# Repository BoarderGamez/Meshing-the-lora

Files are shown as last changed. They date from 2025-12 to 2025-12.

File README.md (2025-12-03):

# Meshing the LoRa
This is a compact LoRa puck for all your needs such as meshtastic. I made this because I'm on my way to getting my ham radio licence and I thought this would be a cool accompanying thing. (also meshtastic is peak)
## Where did this name come from?
I intend to use it for meshtastic so I thought of this name!





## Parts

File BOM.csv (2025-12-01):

Index | LCSC# | MPN | Manufacturer | Package | Description | RoHS | Quantity | MOQ | Multiple | Unit Price($) | Extended Price($) | Product Link | Total Price ($)
1 | C92361 | CL05A474KA5NNNC | Samsung Electro-Mechanics | 402 | 25V 470nF X5R ±10% 0402 Ceramic Capacitors RoHS | yes | 10 | 10 | 10 | 0.0118 | 0.12 | https://www.lcsc.com/product-detail/C92361.html | 0.12
2 | C1525 | CL05B104KO5NNNC | Samsung Electro-Mechanics | 402 | 16V 100nF X7R ±10% 0402 Ceramic Capacitors RoHS | yes | 100 | 100 | 100 | 0.0012 | 0.12 | https://www.lcsc.com/product-detail/C1525.html | 0.24
3 | C1864241 | GJM1555C1H390GB01D | muRata | 402 | 50V 39pF C0G ±2% 0402 Ceramic Capacitors RoHS | yes | 20 | 20 | 20 | 0.0355 | 0.71 | https://www.lcsc.com/product-detail/C1864241.html | 0.95
4 | C76906 | GJM1555C1H3R3BB01D | muRata | 402 | 50V 3.3pF C0G 0402 Ceramic Capacitors RoHS | yes | 50 | 50 | 50 | 0.0166 | 0.83 | https://www.lcsc.com/product-detail/C76906.html | 1.78
5 | C77018 | GRM155R71H102KA01D | muRata | 402 | 50V 1nF X7R ±10% 0402 Ceramic Capacitors RoHS | yes | 100 | 100 | 100 | 0.002 | 0.2 | https://www.lcsc.com/product-detail/C77018.html | 1.98
6 | C76970 | GRM1555C1H470JA01D | muRata | 402 | 50V 47pF C0G ±5% 0402 Ceramic Capacitors RoHS | yes | 100 | 100 | 100 | 0.0022 | 0.22 | https://www.lcsc.com/product-detail/C76970.html | 2.2
7 | C307339 | CL05B473KB5VPNC | Samsung Electro-Mechanics | 402 | 50V 47nF X7R ±10% 0402 Ceramic Capacitors RoHS | yes | 100 | 100 | 100 | 0.0076 | 0.76 | https://www.lcsc.com/product-detail/C307339.html | 2.96
8 | C14445 | CL05A105KP5NNNC | Samsung Electro-Mechanics | 402 | 10V 1uF X5R ±10% 0402 Ceramic Capacitors RoHS | yes | 100 | 100 | 100 | 0.0017 | 0.17 | https://www.lcsc.com/product-detail/C14445.html | 3.13
9 | C76950 | GRM1555C1H150JA01D | muRata | 402 | 50V 15pF C0G ±5% 0402 Ceramic Capacitors RoHS | yes | 100 | 100 | 100 | 0.0025 | 0.25 | https://www.lcsc.com/product-detail/C76950.html | 3.38
10 | C315248 | CL05A106MP5NUNC | Samsung Electro-Mechanics | 402 | 10V 10uF X5R ±20% 0402 Ceramic Capacitors RoHS | yes | 20 | 20 | 20 | 0.0085 | 0.17 | https://www.lcsc.com/product-detail/C315248.html | 3.55
11 | C85815 | BLM15AX102SN1D | muRata | 402 | 490mΩ ±25% 1kΩ@100MHz 0402 Ferrite Beads and Chips RoHS | yes | 100 | 100 | 100 | 0.0055 | 0.55 | https://www.lcsc.com/product-detail/C85815.html | 4.1
12 | C5224443 | 0900FM15K0039E | Johanson Dielectrics | SMD-10P,1.2x2mm | SMD-10P,1.2x2mm Ceramic Filters RoHS | yes | 2 | 1 | 1 | 1.8851 | 3.77 | https://www.lcsc.com/product-detail/C5224443.html | 7.87
13 | C3025063 | USB4105-GF-A-060 | Global Connector Technology | SMD | SMD USB, DVI, HDMI Connector Assemblies RoHS | yes | 2 | 1 | 1 | 1.0013 | 2 | https://www.lcsc.com/product-detail/C3025063.html | 9.87
14 | C3221788 | LQW15DN150M00D | muRata | 402 | 15uH 100mA 0402 Fixed Inductors RoHS | yes | 2 | 1 | 1 | 1.1864 | 2.37 | https://www.lcsc.com/product-detail/C3221788.html | 12.24
15 | C337956 | LQW15AN9N1H00D | muRata | 402 | 9.1nH Unshielded Inductor 0402 Fixed Inductors RoHS | yes | 10 | 10 | 10 | 0.0388 | 0.39 | https://www.lcsc.com/product-detail/C337956.html | 12.63
16 | C22334 | LQW15AN47NG00D | muRata | 402 | 47nH Unshielded Inductor 0402 Fixed Inductors RoHS | yes | 20 | 20 | 20 | 0.0365 | 0.73 | https://www.lcsc.com/product-detail/C22334.html | 13.36
17 | C413063 | ERJ2RKF1000X | PANASONIC | 402 | 100mW 100Ω ±100ppm/℃ Thick Film Resistor ±1% 0402 Chip Resistor - Surface Mount RoHS | yes | 100 | 100 | 100 | 0.0047 | 0.47 | https://www.lcsc.com/product-detail/C413063.html | 13.83
18 | C191123 | ERJ2RKF1002X | PANASONIC | 402 | 100mW 10kΩ 50V ±100ppm/℃ Thick Film Resistor ±1% 0402 Chip Resistor - Surface Mount RoHS | yes | 100 | 100 | 100 | 0.0045 | 0.45 | https://www.lcsc.com/product-detail/C191123.html | 14.28
19 | C2076786 | ERJ2RKF27R4X | PANASONIC | 402 | 100mW 27.4Ω 50V ±100ppm/℃ Thick Film Resistor ±1% 0402 Chip Resistor - Surface Mount RoHS | yes | 50 | 50 | 50 | 0.0057 | 0.29 | https://www.lcsc.com/product-detail/C2076786.html | 14.57
20 | C242161 | ERJ2RKF1001X | PANASONIC | 402 | 100mW 1kΩ ±100ppm/℃ Thick Film Resistor ±1% 0402 Chip Resistor - Surface Mount RoHS | yes | 100 | 100 | 100 | 0.0049 | 0.49 | https://www.lcsc.com/product-detail/C242161.html | 15.06
21 | C105872 | RC0402FR-075K1L | YAGEO | 402 | 5.1kΩ 62.5mW 50V ±100ppm/℃ Thick Film Resistor ±1% 0402 Chip Resistor - Surface Mount RoHS | yes | 100 | 100 | 100 | 0.0007 | 0.07 | https://www.lcsc.com/product-detail/C105872.html | 15.13
22 | C2689642 | PTS636SK25SMTRLFS | C&K | SMD,6x3.5mm | 12V Rectangular Button SPST-NO 50mA SMD,6x3.5mm Tactile Switches RoHS | yes | 5 | 5 | 5 | 0.3601 | 1.8 | https://www.lcsc.com/product-detail/C2689642.html | 16.93
23 | C191341 | SX1262IMLTRT | SEMTECH | QFN-24-EP(4x4) | 300Kbps General Purpose ISM <1 GHz SPI -148dBm 150MHz~960MHz QFN-24-EP(4x4) RF Transceiver ICs RoHS | yes | 1 | 1 | 1 | 3.1633 | 3.16 | https://www.lcsc.com/product-detail/C191341.html | 20.09
24 | C2040 | RP2040 | Raspberry Pi | LQFN-56(7x7) | 133MHz 30 LQFN-56(7x7) Microcontrollers RoHS | yes | 1 | 1 | 1 | 0.9482 | 0.95 | https://www.lcsc.com/product-detail/C2040.html | 21.04
25 | C97521 | W25Q128JVSIQ | Winbond | SOIC-8-208mil | 128Mbit 2.7V~3.6V 133MHz SPI SOIC-8-208mil Memory (ICs) RoHS | yes | 1 | 1 | 1 | 1.8032 | 1.8 | https://www.lcsc.com/product-detail/C97521.html | 22.84
26 | C51118 | AP2112K-3.3TRG1 | DIODES | SOT-25-5 | 65dB@(1kHz) Positive Fixed 3.3V SOT-25-5 Voltage Regulators - Linear, Low Drop Out (LDO) Regulators RoHS | yes | 5 | 5 | 5 | 0.1344 | 0.67 | https://www.lcsc.com/product-detail/C51118.html | 23.51
27 | C470892 | PE4259-63 | pSemi | SC-70-6 | 30dB 0.35dB SC-70-6 RF Switches RoHS | yes | 1 | 1 | 1 | 0.5777 | 0.58 | https://www.lcsc.com/product-detail/C470892.html | 24.09
28 | C276421 | ABM8G-12.000MHZ-B4Y-T | ABRACON | SMD3225-4P | 10pF SMD3225-4P Crystals RoHS | yes | 2 | 1 | 1 | 0.454 | 0.91 | https://www.lcsc.com/product-detail/C276421.html | 25
29 | C5187559 | ABM8G-32.000MHZ-B4Y-T | ABRACON | SMD3225-4P | SMD3225-4P Crystals RoHS | yes | 2 | 1 | 1 | 0.7108 | 1.42 | https://www.lcsc.com/product-detail/C5187559.html | 26.42
30 | N/A | Shipping global direct |  |  |  |  |  |  |  |  | 9.13 |  | 35.55
31 | N/A | JLCPCB excl shipping |  |  | green+stencil |  |  |  |  |  | 14.08 |  | 49.63
32 |  | Shipping europacket bc cheaper than standard direct |  |  | 1 eur cheaper approx |  |  |  |  |  | 20.36 |  | 69.99
33 |  | Customs |  |  |  |  |  |  |  |  | 8.3 |  | 78.29

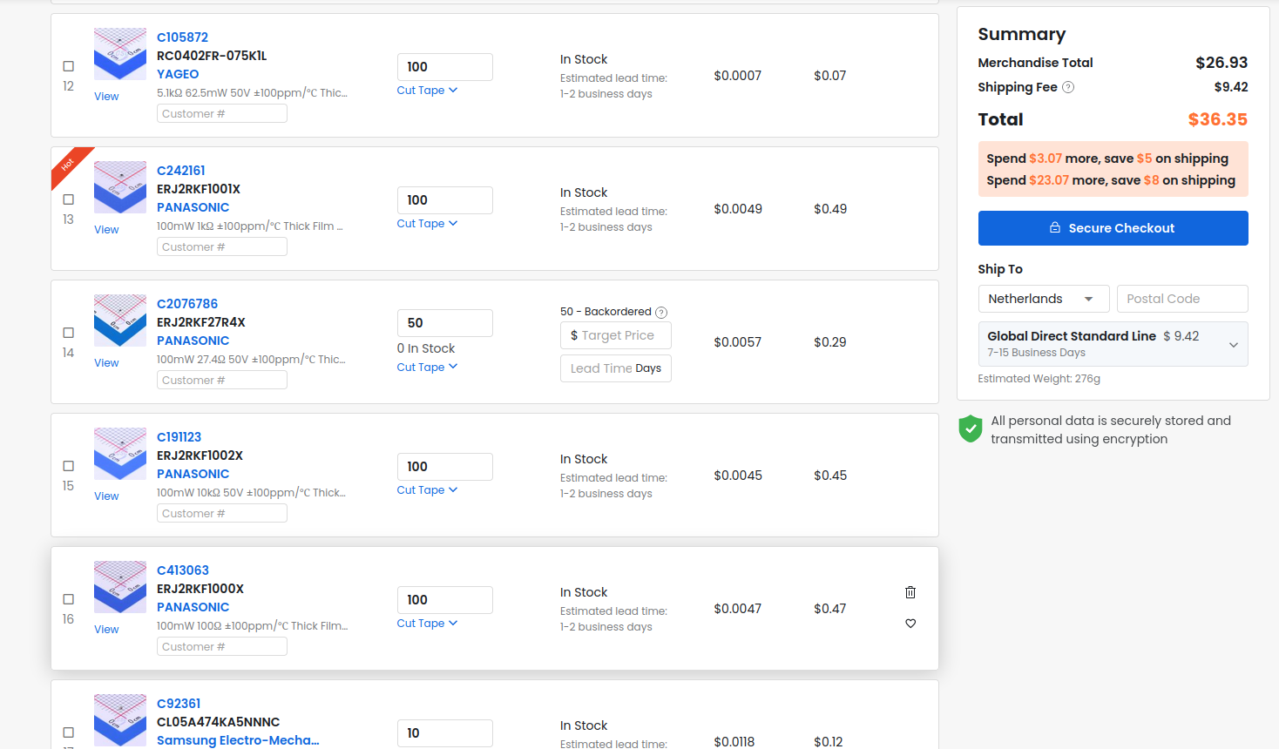
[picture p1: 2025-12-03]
costs/Screenshot from 2025-12-03 13-56-53.png

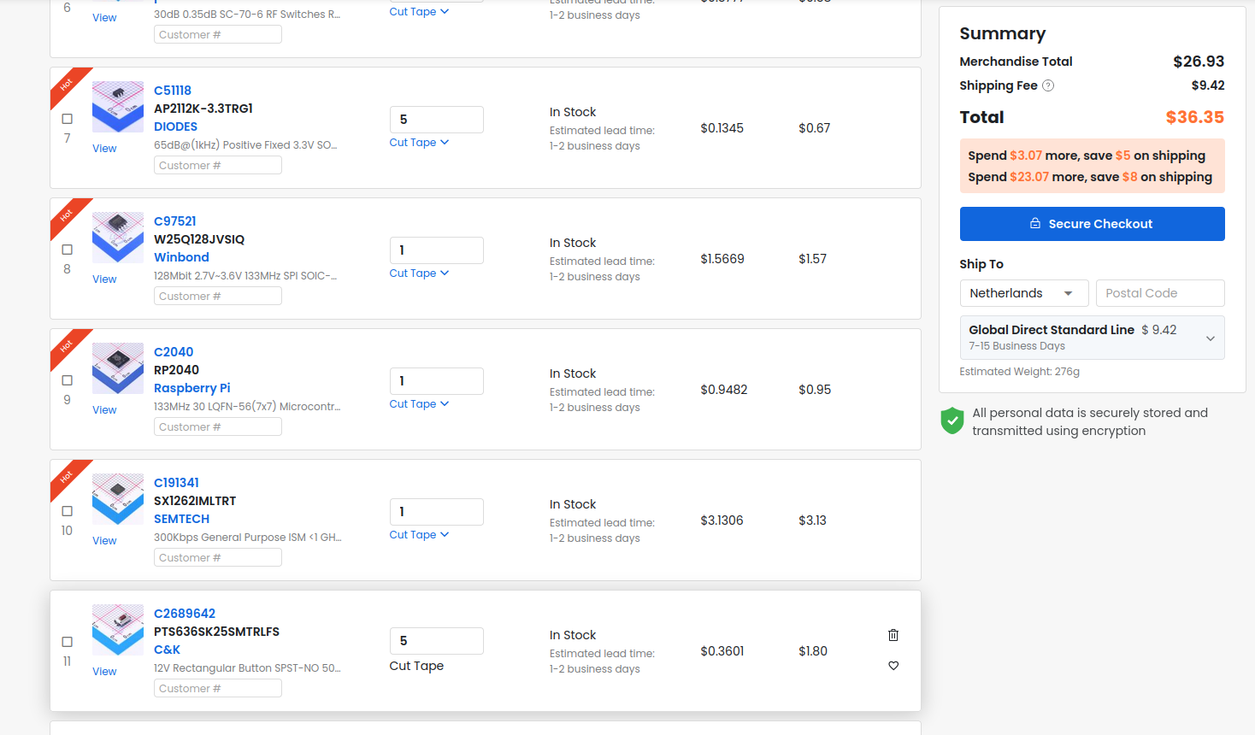
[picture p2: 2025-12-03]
costs/Screenshot from 2025-12-03 13-56-49.png

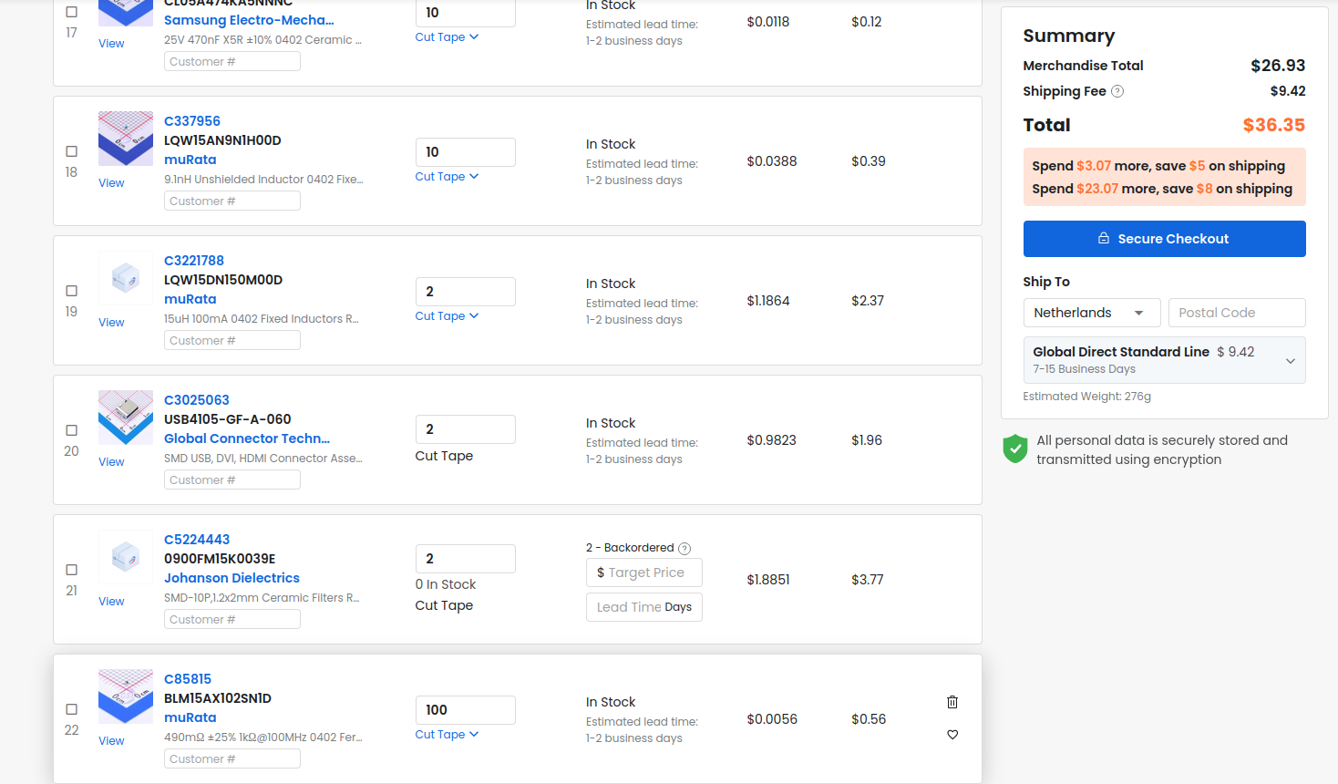
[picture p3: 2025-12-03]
costs/Screenshot from 2025-12-03 13-56-58.png

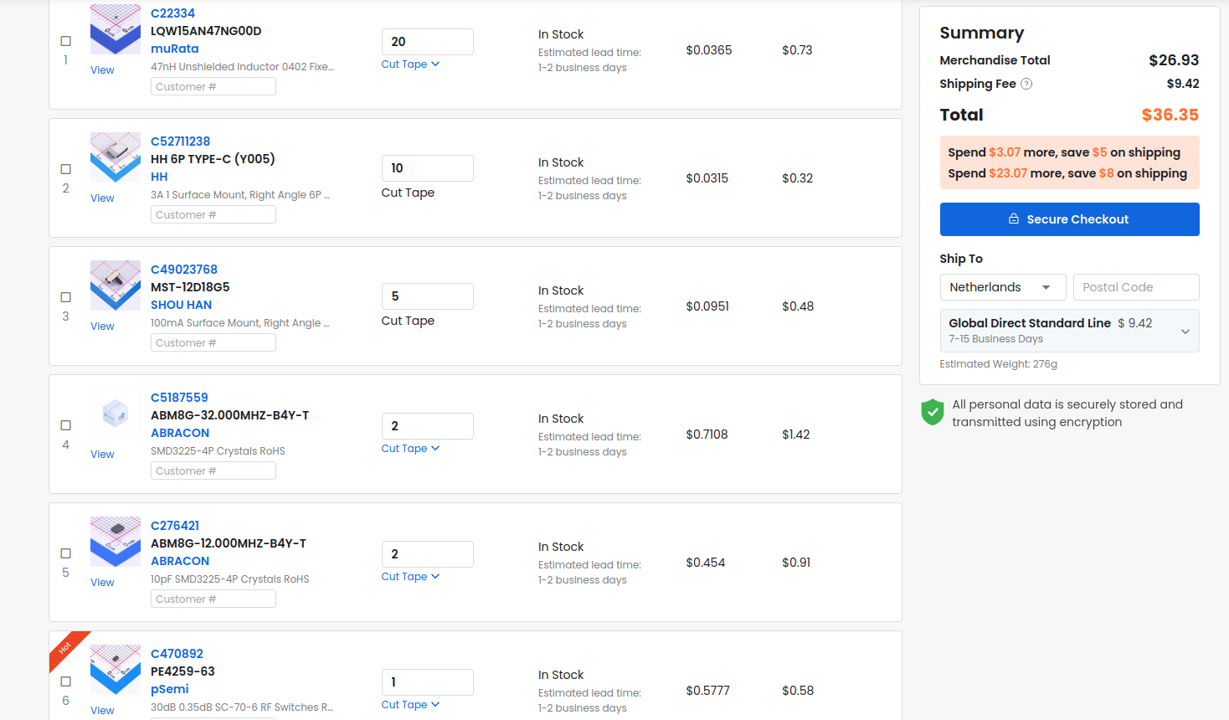
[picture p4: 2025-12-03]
costs/Screenshot from 2025-12-03 13-56-42.png

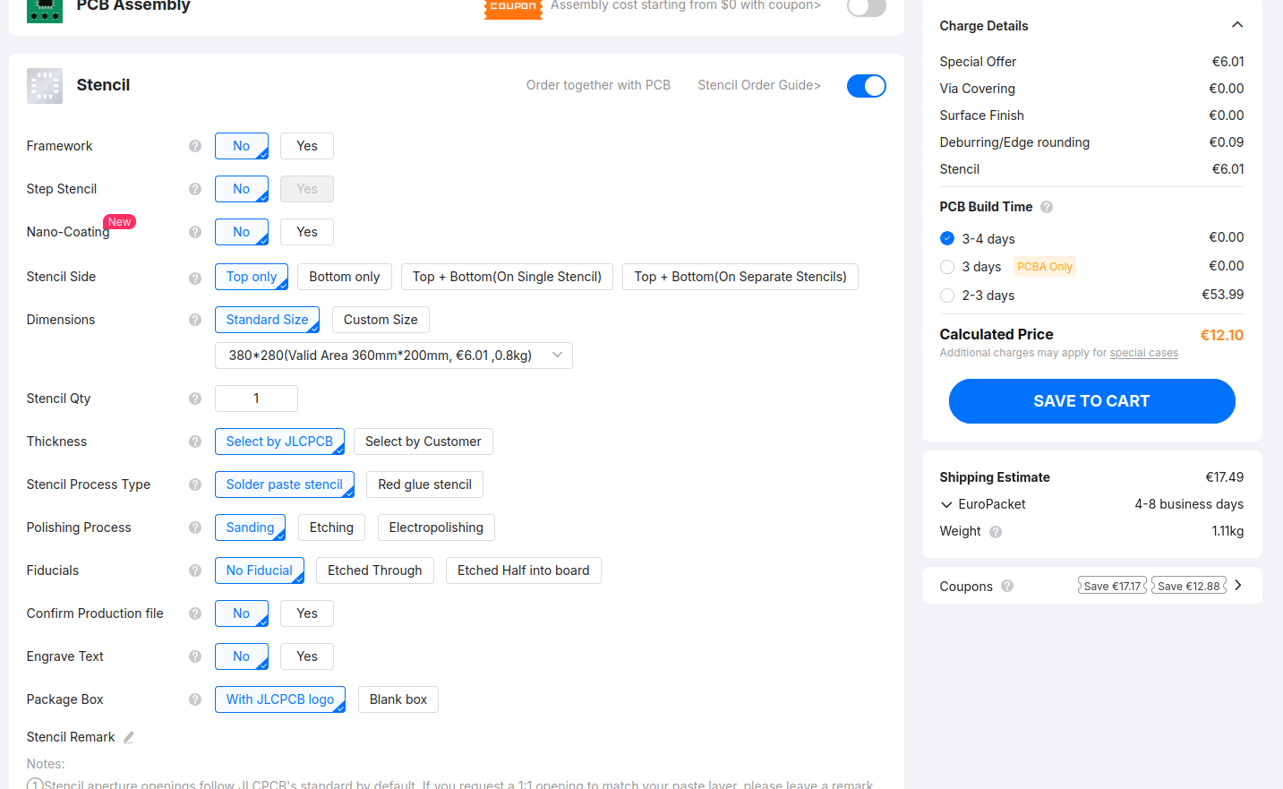
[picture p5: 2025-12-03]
costs/Screenshot from 2025-12-03 14-10-08.png

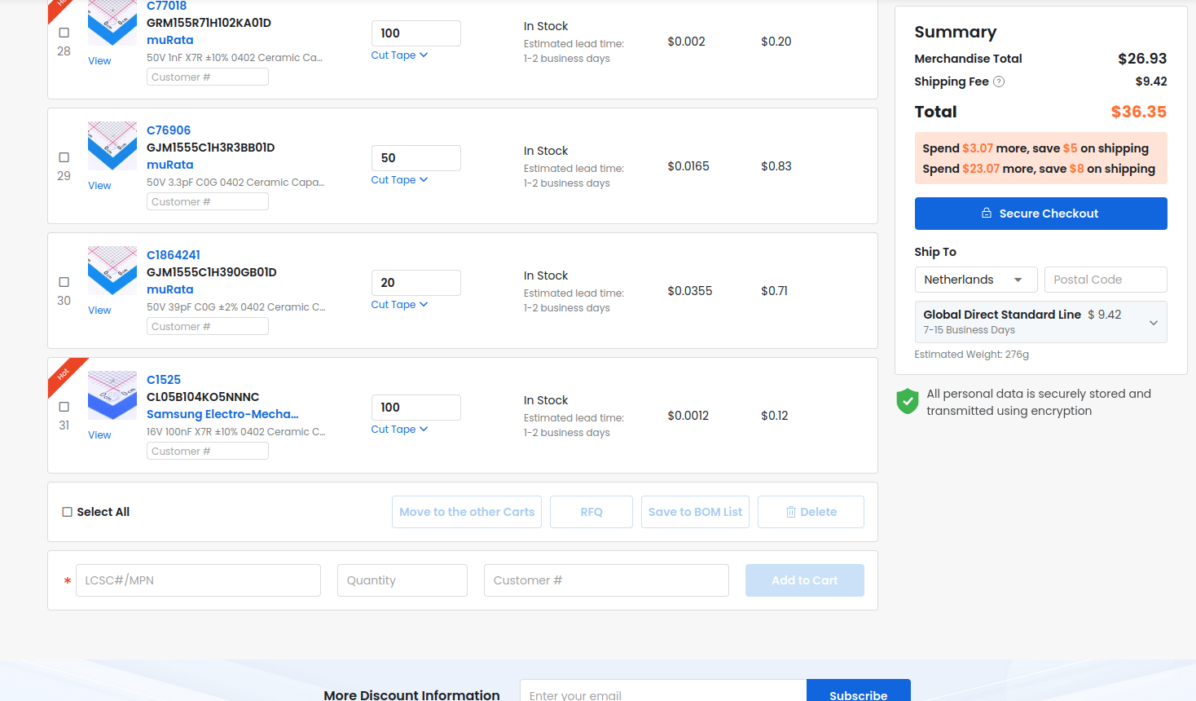
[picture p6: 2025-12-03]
costs/Screenshot from 2025-12-03 13-57-06.png

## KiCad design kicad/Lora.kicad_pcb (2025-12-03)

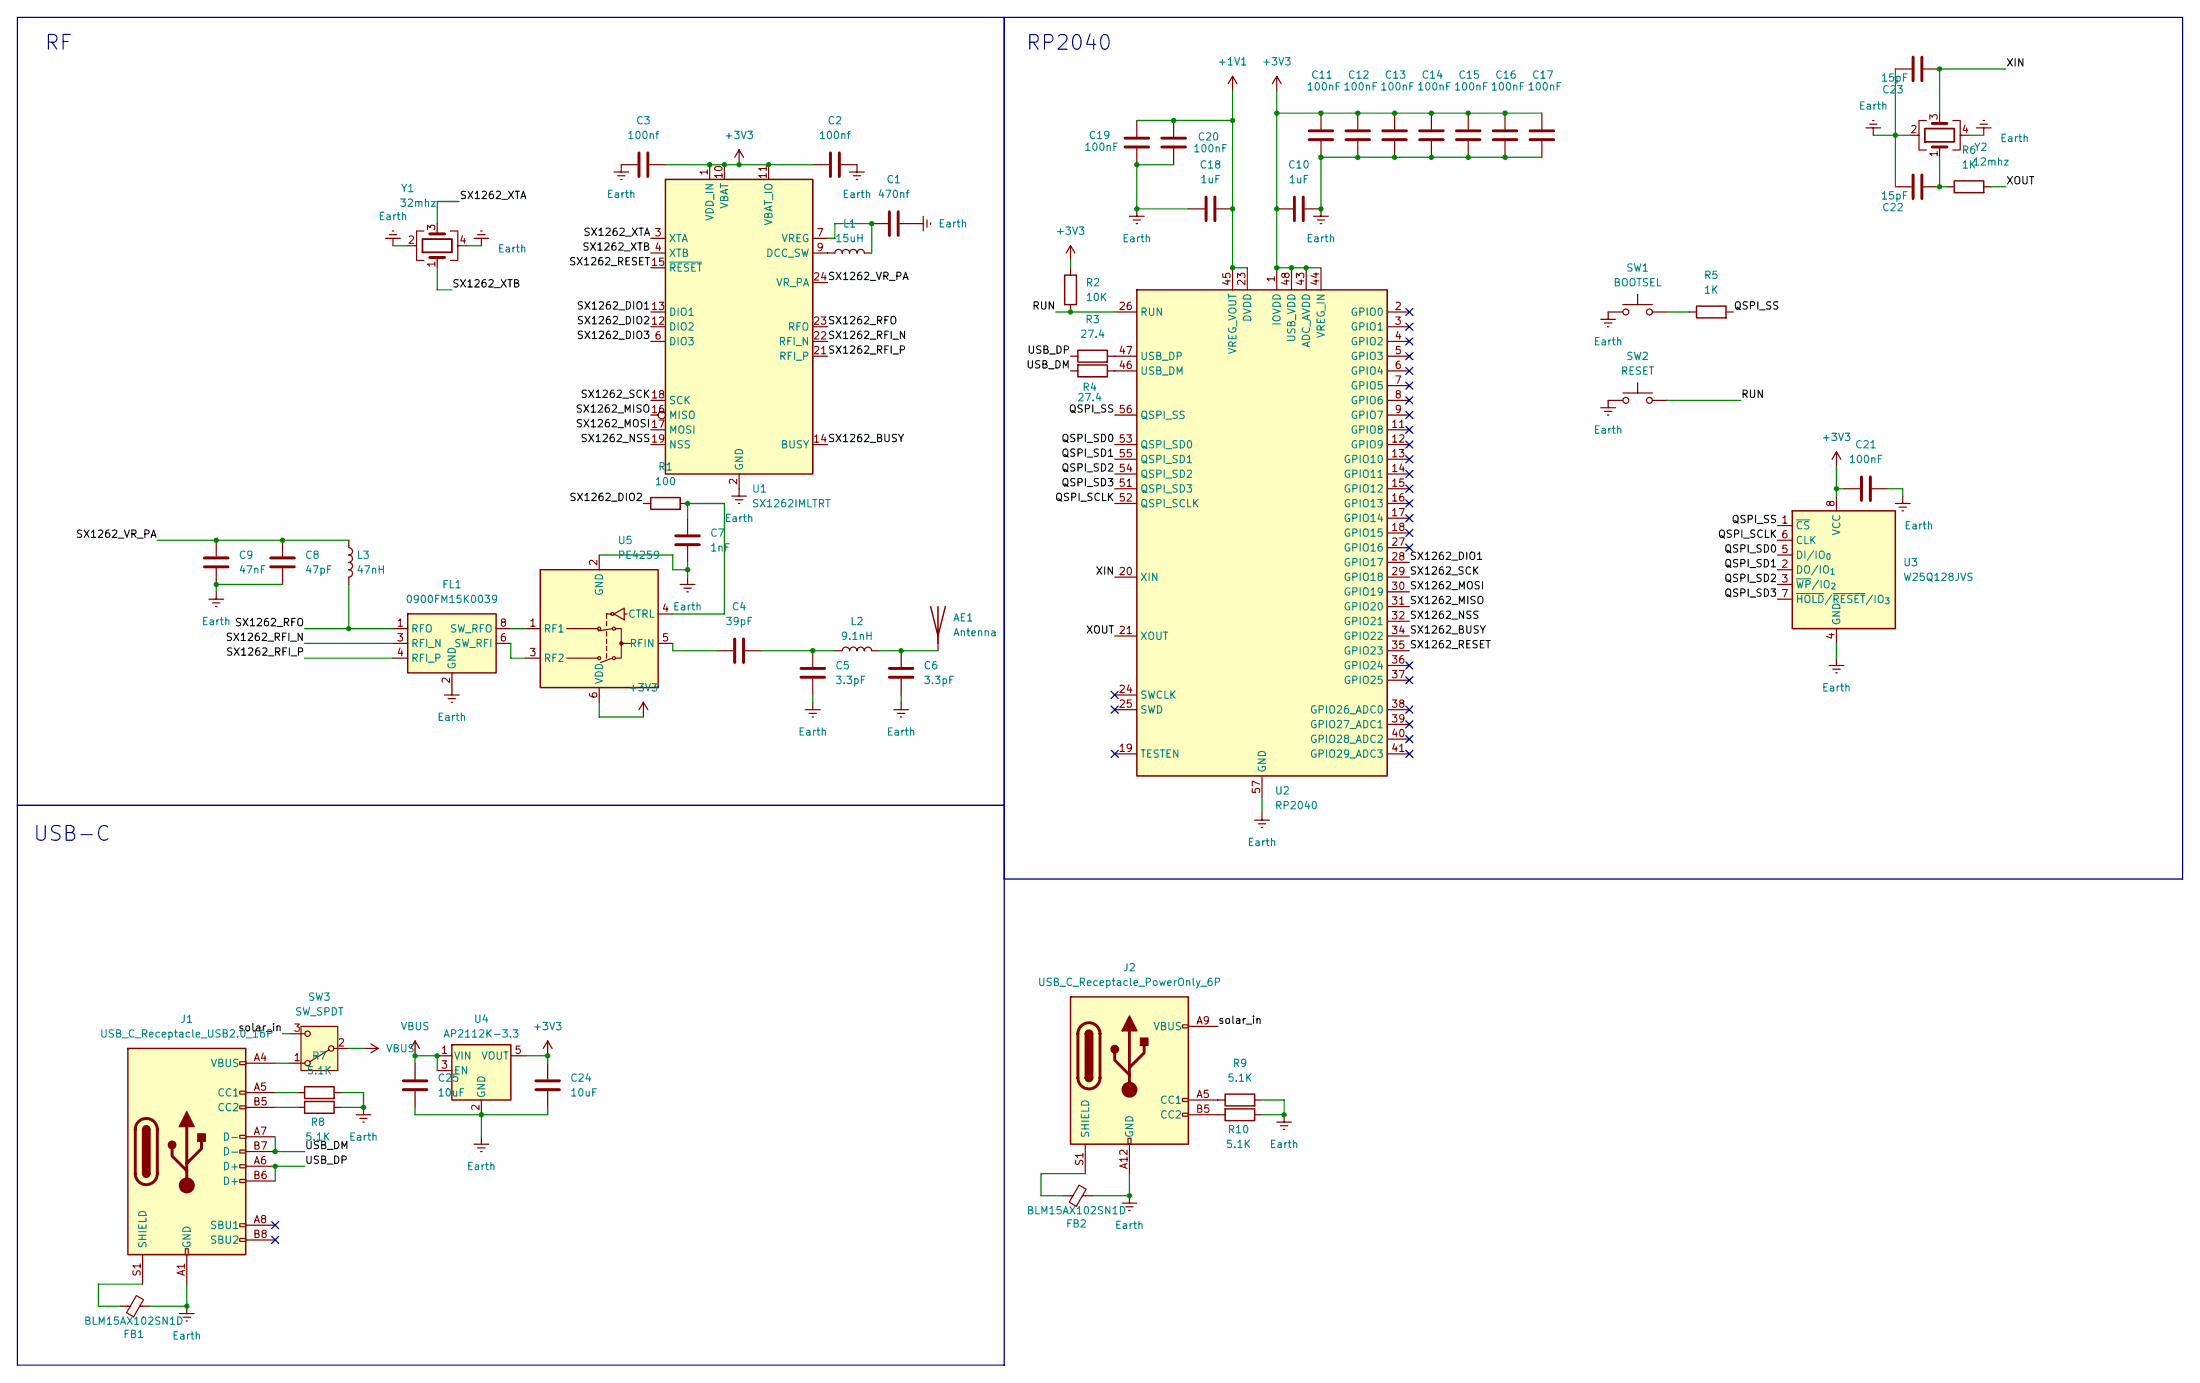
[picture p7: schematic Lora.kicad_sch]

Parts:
AE1: Antenna; PinSocket_1x01_P2.54mm_Vertical
C1: 470nf; C_0402_1005Metric
C2, C3: 100nf; C_0402_1005Metric
C4: 39pF; C_0402_1005Metric
C5, C6: 3.3pF; C_0402_1005Metric
C7: 1nF; C_0402_1005Metric
C8: 47pF; C_0402_1005Metric
C9: 47nF; C_0402_1005Metric
C10, C18: 1uF; C_0402_1005Metric
C11, C12, C13, C14, C15, C16, C17, C19, C20, C21: 100nF; C_0402_1005Metric
C22, C23: 15pF; C_0402_1005Metric
C24, C25: 10uF; C_0402_1005Metric
FB1, FB2: BLM15AX102SN1D; L_0402_1005Metric
FL1: 0900FM15K0039; Balun_Johanson_0900FM15K0039
J1: USB_C_Receptacle_USB2.0_16P; USB_C_Receptacle_GCT_USB4105-xx-A_16P_TopMnt_Horizontal
J2: USB_C_Receptacle_PowerOnly_6P; USB_C_Receptacle_GCT_USB4125-xx-x_6P_TopMnt_Horizontal
L1: 15uH; L_0402_1005Metric
L2: 9.1nH; L_0402_1005Metric
L3: 47nH; L_0402_1005Metric
R1: 100; R_0402_1005Metric
R2: 10K; R_0402_1005Metric
R3, R4: 27.4; R_0402_1005Metric
R5, R6: 1K; R_0402_1005Metric
R7, R8, R9, R10: 5.1K; R_0402_1005Metric
SW1: BOOTSEL; SW_Tactile_SPST_NO_Straight_CK_PTS636Sx25SMTRLFS
SW2: RESET; SW_Tactile_SPST_NO_Straight_CK_PTS636Sx25SMTRLFS
SW3: SW_SPDT; SW_SPDT_CK_JS102011SAQN
U1: SX1262IMLTRT; QFN-24-1EP_4x4mm_P0.5mm_EP2.6x2.6mm
U2: RP2040; QFN-56-1EP_7x7mm_P0.4mm_EP3.2x3.2mm
U3: W25Q128JVS; SOIC-8_5.3x5.3mm_P1.27mm
U4: AP2112K-3.3; SOT-23-5
U5: PE4259; SOT-363_SC-70-6
Y1: 32mhz; Crystal_SMD_3225-4Pin_3.2x2.5mm
Y2: 12mhz; Crystal_SMD_Abracon_ABM8G-4Pin_3.2x2.5mm

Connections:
+1V1: C18.2, C19.1, C20.1, U2.23 (DVDD), U2.45 (VREG_VOUT), U2.50 (DVDD)
+3V3: C2.1, C3.2, C10.1, C11.1, C12.1, C13.1, C14.1, C15.1, C16.1, C17.1, C21.1, C24.1, R2.1, U1.1 (VDD_IN), U1.10 (VBAT), U1.11 (VBAT_IO), U2.1 (IOVDD), U2.10 (IOVDD), U2.22 (IOVDD), U2.33 (IOVDD), U2.42 (IOVDD), U2.43 (ADC_AVDD), U2.44 (VREG_IN), U2.48 (USB_VDD), U2.49 (IOVDD), U3.8 (VCC), U4.5 (VOUT), U5.6 (VDD)
/QSPI_SCLK: U2.52 (QSPI_SCLK), U3.6 (CLK)
/QSPI_SD0: U2.53 (QSPI_SD0), U3.5 (DI/IO_{0})
/QSPI_SD1: U2.55 (QSPI_SD1), U3.2 (DO/IO_{1})
/QSPI_SD2: U2.54 (QSPI_SD2), U3.3 (~WP/IO_{2})
/QSPI_SD3: U2.51 (QSPI_SD3), U3.7 (~HOLD/~RESET/IO_{3})
/QSPI_SS: R5.2, U2.56 (QSPI_SS), U3.1 (~CS)
/RUN: R2.2, SW2.2, U2.26 (RUN)
/SX1262_BUSY: U1.14 (BUSY), U2.34 (GPIO22)
/SX1262_DIO1: U1.13 (DIO1), U2.28 (GPIO17)
/SX1262_DIO2: R1.1, U1.12 (DIO2)
/SX1262_DIO3: U1.6 (DIO3)
/SX1262_MISO: U1.16 (MISO), U2.31 (GPIO20)
/SX1262_MOSI: U1.17 (MOSI), U2.30 (GPIO19)
/SX1262_NSS: U1.19 (NSS), U2.32 (GPIO21)
/SX1262_RESET: U1.15 (~RESET), U2.35 (GPIO23)
/SX1262_RFI_N: FL1.3 (RFI_N), U1.22 (RFI_N)
/SX1262_RFI_P: FL1.4 (RFI_P), U1.21 (RFI_P)
/SX1262_RFO: FL1.1 (RFO), L3.2, U1.23 (RFO)
/SX1262_SCK: U1.18 (SCK), U2.29 (GPIO18)
/SX1262_VR_PA: C8.1, C9.1, L3.1, U1.24 (VR_PA)
/SX1262_XTA: U1.3 (XTA), Y1.3
/SX1262_XTB: U1.4 (XTB), Y1.1
/USB_DM: J1.A7 (D-), J1.B7 (D-), R4.2
/USB_DP: J1.A6 (D+), J1.B6 (D+), R3.1
/XIN: C23.2, U2.20 (XIN), Y2.3
/XOUT: R6.2, U2.21 (XOUT)
/solar_in: J2.A9 (VBUS), J2.B9 (VBUS), SW3.3 (C)
Earth: C1.1, C2.2, C3.1, C5.1, C6.2, C7.2, C8.2, C9.2, C10.2, C11.2, C12.2, C13.2, C14.2, C15.2, C16.2, C17.2, C18.1, C19.2, C20.2, C21.2, C22.1, C23.1, C24.2, C25.2, FB1.2, FB2.2, FL1.2 (GND), FL1.5 (GND), FL1.7 (GND), FL1.9 (GND), FL1.10 (GND), J1.A1 (GND), J1.A12 (GND), J1.B1 (GND), J1.B12 (GND), J2.A12 (GND), J2.B12 (GND), R7.2, R8.1, R9.2, R10.1, SW1.1, SW2.1, U1.2 (GND), U1.5 (GND), U1.8 (GND), U1.20 (GND), U1.25 (GND), U2.57 (GND), U3.4 (GND), U4.2 (GND), U5.2 (GND), Y1.2, Y1.4, Y2.2, Y2.4
unnamed: AE1.1 (A), C6.1, L2.2
unnamed: C4.2, C5.2, L2.1
unnamed: C22.2, R6.1, Y2.1
unnamed: FL1.6 (SW_RFI), U5.3 (RF2)
unnamed: FL1.8 (SW_RFO), U5.1 (RF1)
unnamed: J1.A5 (CC1), R7.1
unnamed: J1.B5 (CC2), R8.2
unnamed: FB1.1, J1.S1 (SHIELD)
unnamed: J2.A5 (CC1), R9.1
unnamed: J2.B5 (CC2), R10.2
unnamed: FB2.1, J2.S1 (SHIELD)
unnamed: R5.1, SW1.2
unnamed: J1.A4 (VBUS), J1.A9 (VBUS), J1.B4 (VBUS), J1.B9 (VBUS), SW3.1 (A)
unnamed: L1.1, U1.9 (DCC_SW)
unnamed: C1.2, L1.2, U1.7 (VREG)
unnamed: R4.1, U2.46 (USB_DM)
unnamed: R3.2, U2.47 (USB_DP)
unnamed: C7.1, R1.2, U5.4 (CTRL)
unnamed: C4.1, U5.5 (RFIN)
VBUS: C25.1, SW3.2 (B), U4.1 (VIN), U4.3 (EN)

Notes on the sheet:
USB-C
RP2040

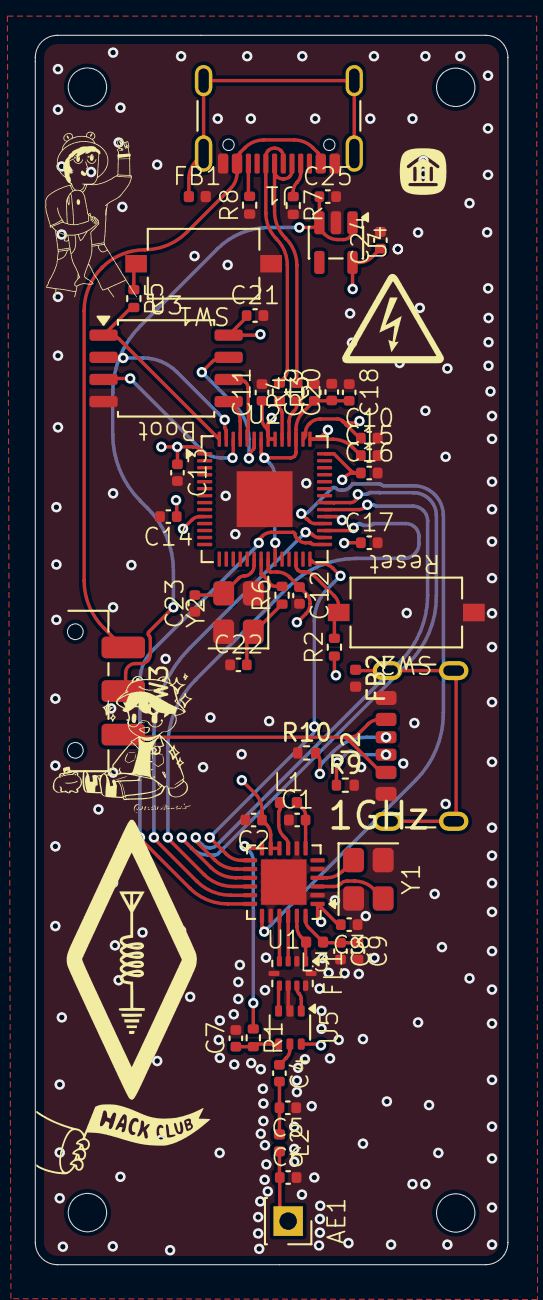
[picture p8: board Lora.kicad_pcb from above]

Board: 4 copper layers, 27.1 x 70.5 mm, 54 parts (0 on the bottom side), 49 nets.

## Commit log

2025-11-28 dun x2
    [Lora.kicad_pcb]
2025-11-28 acc dun
    [Lora.kicad_pcb, Lora.kicad_sch]
